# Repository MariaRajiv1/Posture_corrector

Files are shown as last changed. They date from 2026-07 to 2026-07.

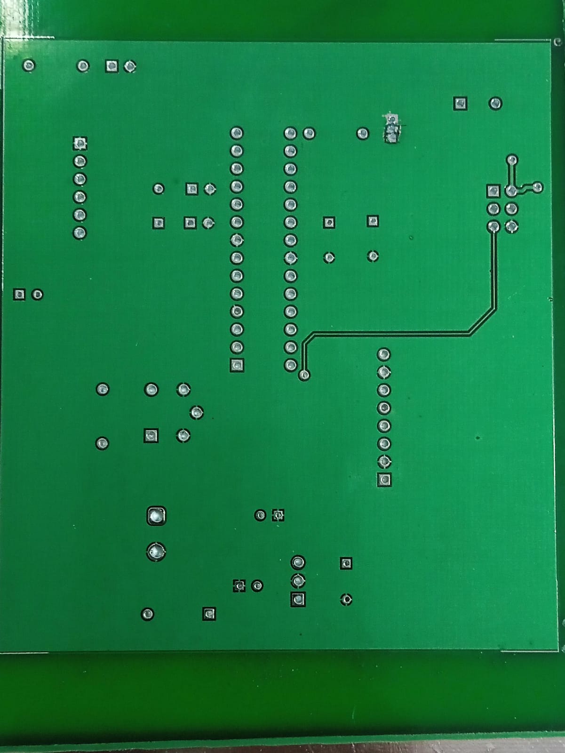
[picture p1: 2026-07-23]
images/fabricated pcb bottom layer.jpeg

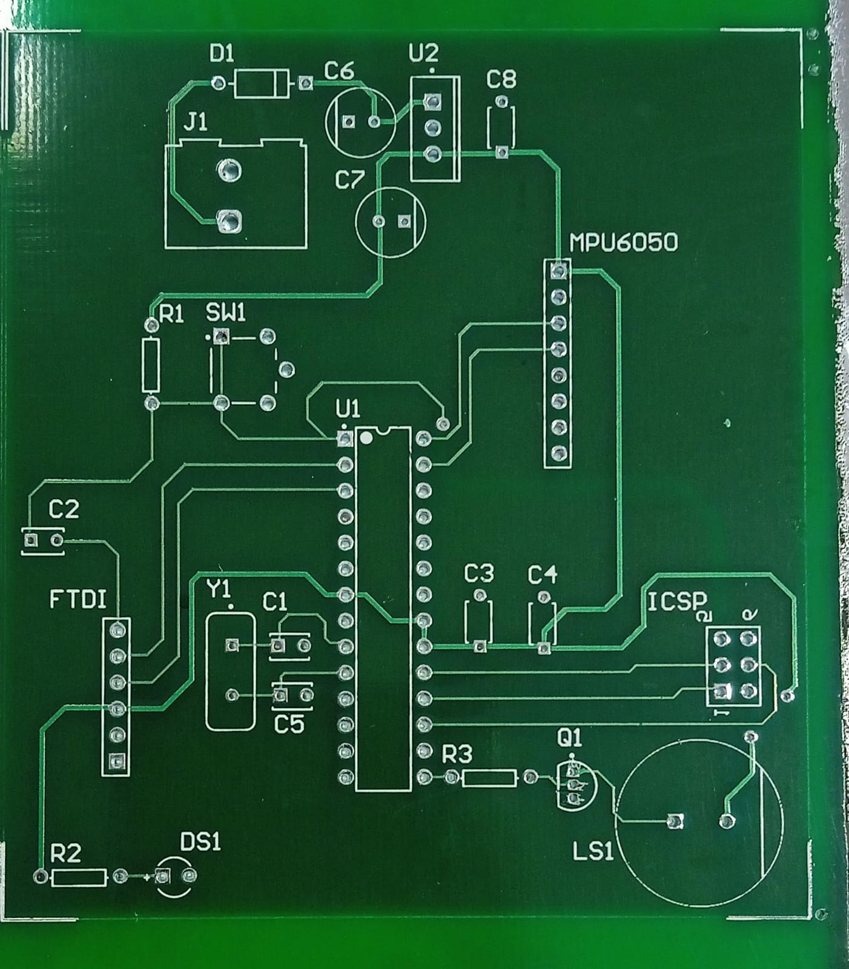
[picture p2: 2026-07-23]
images/fabricated pcb top layer.jpeg

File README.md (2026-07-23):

# Posture Corrector using ATmega328P and MPU6050

A wearable embedded system designed to monitor user posture in real time using the MPU6050 inertial measurement unit (IMU) and an ATmega328P microcontroller. The system detects prolonged poor posture and provides immediate feedback through an alert mechanism, encouraging users to maintain proper posture during daily activities.

This project was developed using a custom-designed PCB, demonstrating practical skills in embedded systems, PCB design, sensor interfacing, and hardware implementation.

---

## Features

- Real-time posture monitoring
- Slouch detection using MPU6050 IMU
- ATmega328P-based embedded system
- Custom PCB design
- Immediate posture correction alert
- Compact, wearable design
- Low-cost implementation

---

## Hardware Components

| Component | Description |
|---|---|
| ATmega328P | Main microcontroller |
| MPU6050 | 3-axis Accelerometer & Gyroscope |
| Buzzer / Vibration Motor | User alert mechanism |
| Voltage Regulator | Stable power supply |
| Battery | Portable power source |
| Custom PCB | Designed for compact implementation |

---

## Software Used

- Arduino IDE
- Embedded C
- I²C Communication Protocol
- MPU6050 Library

---

## Working Principle

1. The MPU6050 continuously measures the orientation of the user's upper body.
2. Sensor data is transmitted to the ATmega328P through I²C communication.
3. The microcontroller processes the orientation data and compares it with predefined posture thresholds.
4. If poor posture is maintained beyond the set duration, the system activates the alert mechanism.
5. The user corrects their posture, after which the system resumes monitoring.

---

## Repository Structure

```
Posture-Corrector/
│
├── README.md
├── docs/
├── hardware/
│   ├── Schematics/
│   └── PCB/
├── Gerbers/
├── firmware/
├── images/
├── reports/
└── results/

---

## Project Images

- Final Device
- Custom PCB
- Hardware Assembly
- Testing Setup
- Working Demonstration

---

## Results

- Successfully detects incorrect posture.
- Generates real-time alerts for prolonged slouching.
- Compact hardware implementation using a custom PCB.
- Suitable for wearable posture monitoring applications.

---

## Future Improvements

- Bluetooth connectivity
- Mobile application integration
- Rechargeable battery management
- Data logging
- Machine learning-based posture classification
- Miniaturized wearable enclosure

---

## Skills Demonstrated

- Embedded Systems
- PCB Design
- Sensor Interfacing
- ATmega328P Programming
- I²C Communication
- Hardware Debugging
- Wearable Electronics

---

## Authors

This project was developed by:

- Maria Rajiv
- Neha Savy
- Pavithra Mohan
- Suryadev G
  
B.Tech in Electronics and Communication Engineering

Mar Athanasius College of Engineering

---

## Acknowledgements

Special thanks to the project guide and team members for their support throughout the development of this project.

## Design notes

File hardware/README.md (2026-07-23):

# Hardware

This directory contains the complete hardware design files for the **Posture Corrector using ATmega328P and MPU6050**.

The hardware was developed to provide a compact, low-cost, and wearable solution for real-time posture monitoring. A custom printed circuit board (PCB) was designed to integrate the microcontroller, motion sensor, power supply, and supporting circuitry into a single embedded system.

## Directory Structure

### 📂 Schematics
Contains the complete circuit schematic of the posture corrector, including the ATmega328P microcontroller, MPU6050 IMU, power supply, programming interface, and alert circuitry.

### 📂 PCB
Contains the PCB layout, routing, board design files, and 3D renderings used during the hardware development process.

## Hardware Specifications

- **Microcontroller:** ATmega328P
- **Motion Sensor:** MPU6050 (3-axis Accelerometer + 3-axis Gyroscope)
- **Communication Protocol:** I²C
- **Alert Mechanism:** Buzzer / Vibration Motor
- **Power Supply:** Battery-powered
- **PCB Type:** Custom two-layer PCB

## Design Workflow

1. Circuit design and component selection
2. Schematic development
3. PCB layout and routing
4. Design Rule Check (DRC)
5. Gerber file generation
6. PCB fabrication
7. Component assembly and soldering
8. Hardware testing and validation

## Purpose

The hardware design demonstrates practical implementation of embedded electronics, including sensor interfacing, custom PCB design, power management, and wearable system development.

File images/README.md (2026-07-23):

# Images

This directory contains photographs and visual assets related to the **Posture Corrector using ATmega328P and MPU6050** project.

The images provide a visual overview of the hardware development, PCB fabrication, assembly process, and the final working prototype.

---

## Contents

### Final Prototype
Photographs of the completed wearable posture corrector.

### PCB
Images of the fabricated printed circuit board, including top and bottom views.

### Hardware Assembly
Photographs of the assembled electronic components and wiring.

### PCB Layout and 3D View
Rendered images of the PCB layout and 3D model generated during the design phase.

---

## Purpose

The images included in this directory document the development process and provide visual reference for the hardware implementation, making it easier to understand the overall design and construction of the project.

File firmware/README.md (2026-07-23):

# Firmware

This directory contains the firmware developed for the **Posture Corrector using the ATmega328P and MPU6050**.

The firmware is responsible for acquiring motion data from the MPU6050 IMU, processing the sensor readings to determine the user's posture, and activating an alert when poor posture is maintained beyond a predefined threshold. The software is optimized for real-time operation on the ATmega328P microcontroller.

---

## Features

- Real-time posture monitoring
- MPU6050 accelerometer and gyroscope interfacing
- I²C communication with the IMU
- Sensor data processing
- Posture angle calculation
- Configurable posture threshold
- Timer-based slouch detection
- Alert generation using a buzzer or vibration motor

---

## Development Environment

- **Microcontroller:** ATmega328P
- **Programming Language:** Embedded C/C++
- **Development Platform:** Arduino IDE
- **Communication Protocol:** I²C

---

## Firmware Workflow

1. Initialize the ATmega328P and MPU6050.
2. Read accelerometer and gyroscope data from the IMU.
3. Process the sensor data to determine the user's orientation.
4. Compare the measured posture with the predefined threshold.
5. If poor posture persists for the specified duration, activate the alert mechanism.
6. Continue monitoring until the posture returns to the acceptable range.

---

## Source Code

The firmware source code is provided in this directory and can be compiled and uploaded to the ATmega328P using the Arduino IDE.

---

## Notes

- Ensure the required libraries are installed before compiling the project.
- Verify the I²C connections between the ATmega328P and MPU6050 before uploading the firmware.
- Calibrate the MPU6050 sensor before testing to achieve accurate posture detection.

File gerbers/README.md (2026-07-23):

# Gerber Files

This directory contains the Gerber files generated from the final PCB design of the **Posture Corrector** project.

Gerber files are the standard manufacturing files used by PCB fabrication services to produce the printed circuit board. They include all the information required to manufacture the PCB, such as copper layers, solder mask, silkscreen, board outline, and drill data.

## Contents

- Copper layer files
- Solder mask files
- Silkscreen files
- Board outline
- NC drill files

## Usage

The files in this directory can be compressed into a ZIP archive and uploaded directly to PCB manufacturers such as **JLCPCB**, **PCBWay**, or **Seeed Fusion** for fabrication.

## Notes

- Generated from the final verified PCB layout.
- Ensure all Gerber files and drill files are included before submitting for fabrication.
- Perform a Gerber viewer check to verify the design before manufacturing.

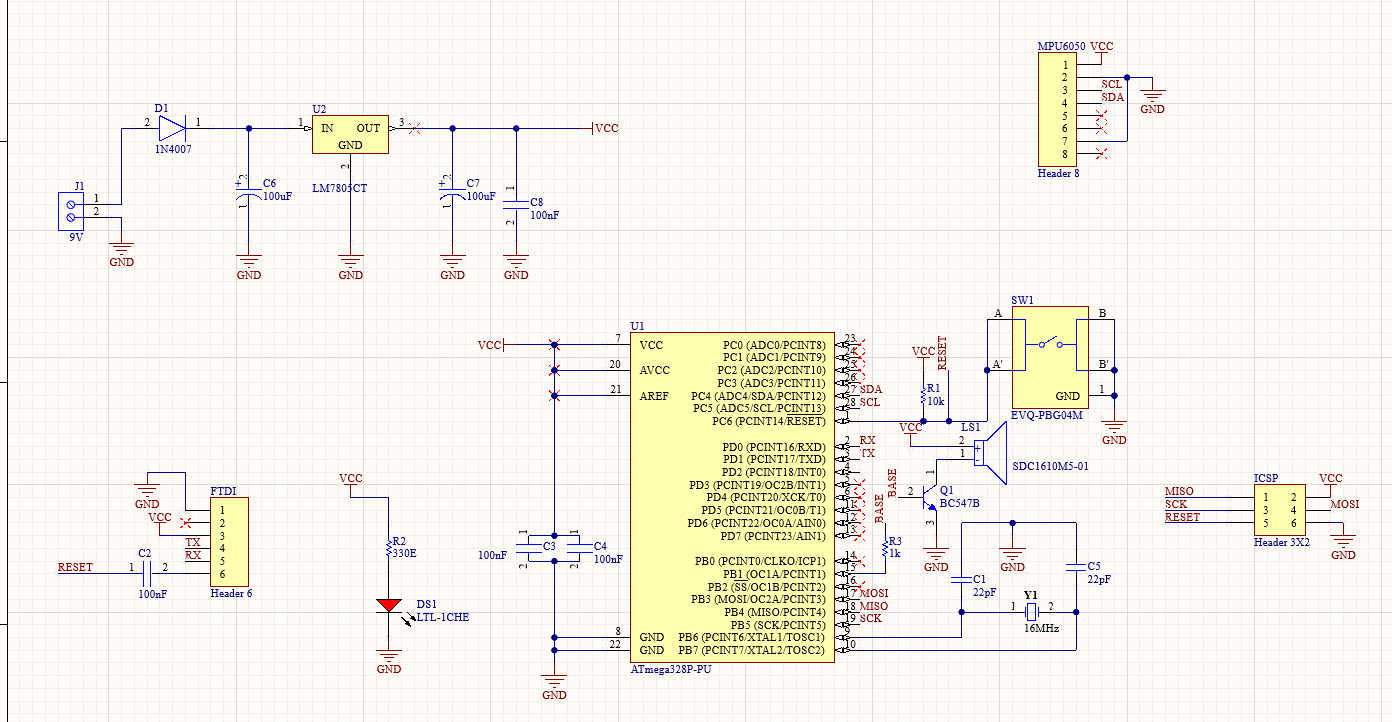
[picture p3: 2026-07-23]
images/schematic.png

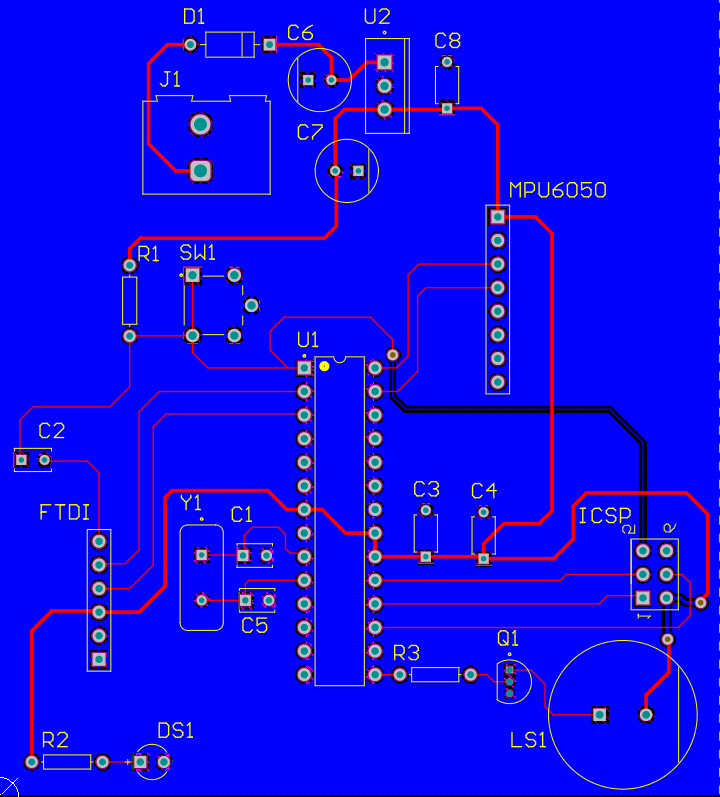
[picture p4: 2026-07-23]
images/pcb_design.png

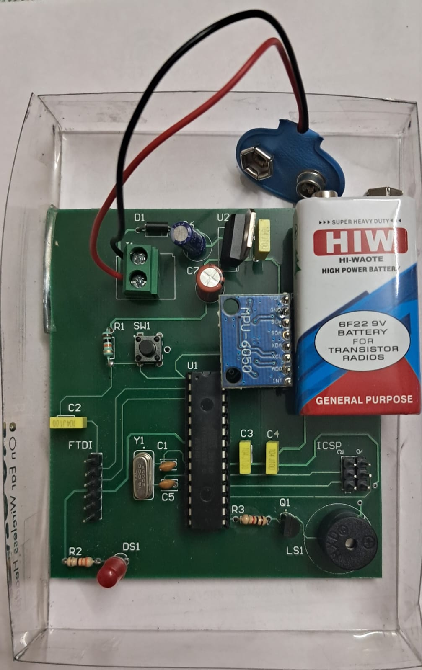
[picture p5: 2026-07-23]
images/completed pcb.jpeg

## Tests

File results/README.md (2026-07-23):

# Results

This directory contains the testing results and performance evaluation of the **Posture Corrector using ATmega328P and MPU6050**.

The results demonstrate the functionality of the system, including posture detection accuracy, alert response, and overall hardware performance under different testing conditions.

---

## Contents

### Functional Testing
Results obtained during system testing to verify correct operation of the hardware and firmware.

### Posture Detection
Observations of the system's ability to distinguish between correct and incorrect posture based on sensor data.

### Alert Mechanism
Verification of the buzzer or vibration motor response when poor posture is maintained beyond the predefined threshold.

### Calibration
Calibration data and test observations used to improve sensor accuracy and reliability.

### Demonstration
Screenshots, photographs, or recorded outputs showcasing the successful operation of the posture correction system.

---

## Summary

The implemented system successfully monitors body posture in real time using the MPU6050 IMU and ATmega328P microcontroller. The device detects prolonged poor posture and provides immediate feedback through the alert mechanism, demonstrating the feasibility of a compact and low-cost wearable posture monitoring solution.

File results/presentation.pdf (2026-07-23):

# MINI PROJECT PRESENTATION

GROUP 10

Maria Rajiv (MAC23EC079)
Neha Savy (MAC23EC096)
Pavithra Mohan (MAC23EC097) Suryadev G (MAC23EC120)

MAR ATHANASIUS COLLEGE OF ENGINEERING, KOTHAMANGALAM

DEPARTMENT OF ELECTRONICS AND COMMUNICATION ENGINEERING

## COURSE CODE : ECD334

## PHASE I & II

# CONTENTS

- Introduction ● Objectives ● Components Required ● Block Diagram ● Working Principle ● Features ● Design & Implementation ● Results ● Challenges ● Applications & Future scope
- Working Principle ● Design ● Components Required ● Circuit Diagram ● Schematic Diagram ● PCB Layout ● Fabrication steps ● Output & Results ● Challenges ● Applications & Future scope

# WHY POSTURE CORRECTION MATTERS ?

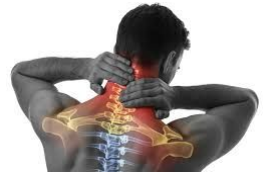
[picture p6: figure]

- Extended sitting is common among students and IT professionals
- Improper posture causes neck pain, back pain, and muscle fatigue
- Sustained poor posture may lead to cervical spondylosis, back strain, and stiffness

# WHAT IS CONSIDERED GOOD POSTURE ?

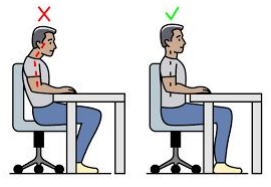
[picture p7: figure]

- Good posture maintains a near-neutral spine
- A small natural curve in the back is maintained
- Posture is personalized, not based on a single fixed angle

# OBJECTIVES

- To design a wearable posture correction system
- To implement posture detection using MPU6050 sensor data
- To process orientation data using the ATmega328P microcontroller
- To perform baseline calibration for user-specific posture adaptation
- To generate corrective feedback using a buzzer alert system
- To develop a custom-designed PCB for a compact embedded solution
- To validate the system through fabricated hardware testing

# HARDWARE COMPONENTS

- ATmega328P microcontroller
- MPU6050 sensor
- Buzzer
- BC547 transistor
- 7805 voltage regulator
- 16 MHz crystal oscillator
- capacitors, resistors, reset switch
- FTDI and ICSP programming headers
- 9V power input

# BLOCK DIAGRAM

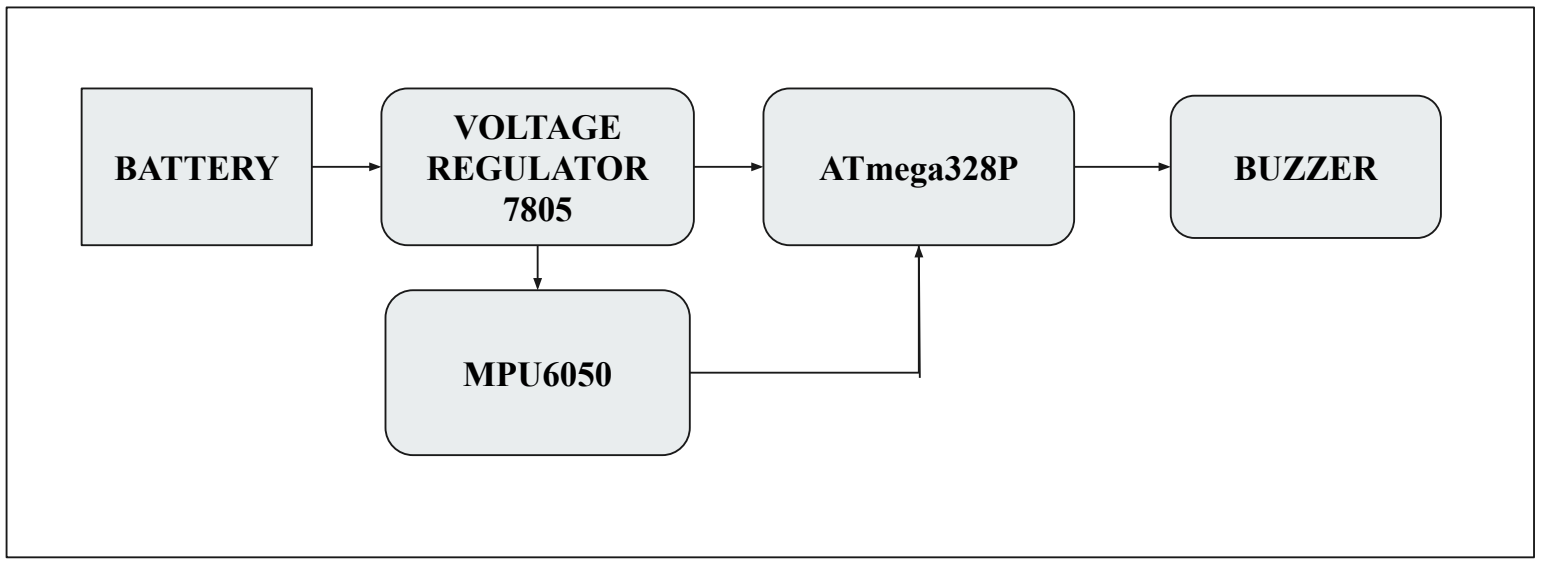
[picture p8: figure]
BATTERY; VOLTAGE REGULATOR 7805; ATmega328P; MPU6050; BUZZER

# WORKING PRINCIPLE

1. Device powers on → a startup beep confirms readiness
2. Good posture is recorded as baseline pitch
3. Sensor continuously measures current tilt
4. Controller computes corrected pitch = current pitch − baseline
5. If slouch exceeds threshold for a 3 seconds, buzzer sounds
6. If posture becomes worse, beep rate increases
7. When posture is corrected, alert stops

# WORKING PRINCIPLE

MPU6050 communicates over I²C and provides:

- Accelerometer output as linear acceleration along X, Y, Z axes (in m/s²)
- Converted into angle (degrees)

Where ay and az are acceleration components

# FEATURES

### 1. Baseline Calibration

- On startup, the user is prompted: "Hold good posture for calibration"
- After a 2-second settle delay, one accelerometer reading is captured
- This pitch value becomes baseline pitch — stored for the entire session
- All subsequent readings are subtracted from this baseline

corrected pitch = current pitch − baseline pitch

# FEATURES

### 2. Decision Logic and Adaptive Alert System

Beep frequency: 2000 Hz, duration: 120 ms

CONDITION | ANGLE | BEEP INTERVAL
Good Posture | <14° | No Beep
Bad Posture | 18-30° | Every 2 seconds
Very Bad Posture | >30° | Every 700 ms

# FEATURES

### 3. False Alert Prevention

- Short-term bending (like picking objects) should not trigger alert
- Solution implemented:

3-second delay before alert

Neutral zone (<5°) resets system

Filtering removes sudden spikes

- Only continuous bad posture triggers buzzer

# SIMULATION USING WOKWI

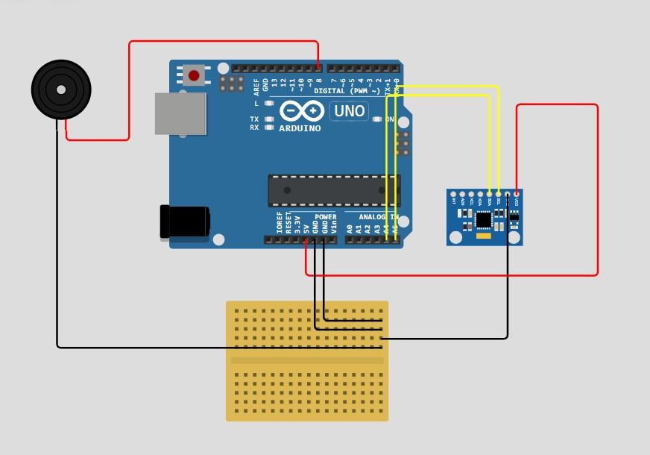
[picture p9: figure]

FIG 1: POSTURE CORRECTOR IMPLEMENTED USING ARDUINO UNO

## SCHEMATIC DESIGN USING ALTIUM

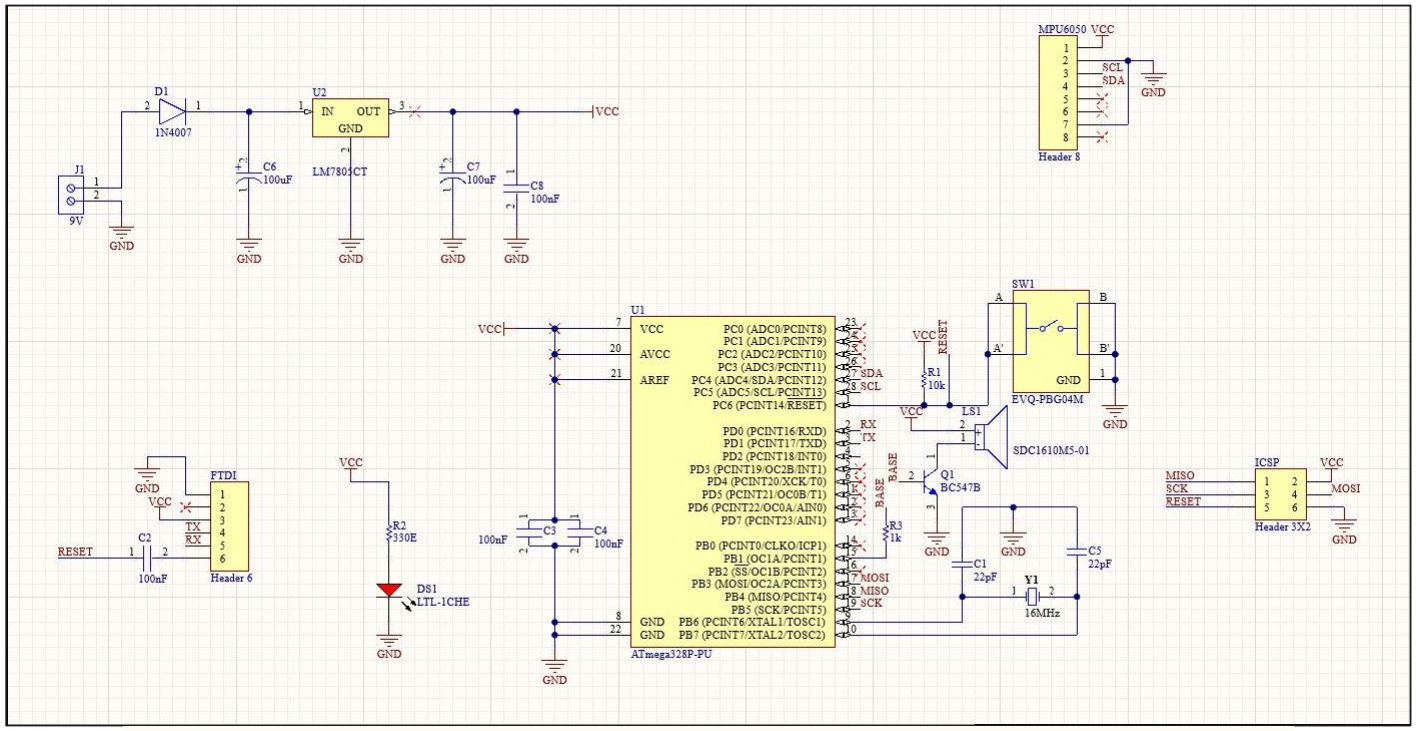
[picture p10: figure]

FIG 2 : SCHEMATIC DESIGN OF POSTURE CORRECTOR USING ATMEGA328P

# CIRCUIT OVERVIEW

### 1. Power Section

Regulated 5V Power Supply

- Input: 9V external supply
- 1N4007 diode — reverse polarity protection, prevents damage if battery is connected backwards
- LM7805 — linear voltage regulator, steps down 9V → stable 5V
- 100µF capacitor — bulk filtering, absorbs low-frequency voltage fluctuations
- 100nF capacitor — high-frequency noise decoupling, keeps supply clean at the IC pins

# CIRCUIT OVERVIEW

### 2. Microcontroller Core

ATmega328P

- Heart of the system — runs all posture logic, timing, and I²C communication
- 16 MHz crystal (Y1) — provides precise clock reference
- 22pF capacitors (C1, C5) — load capacitors for crystal stability

# CIRCUIT OVERVIEW

### 2. MPU6050 Interface

- Communicates with ATmega328P over I²C protocol (2-wire)
- SDA → PC4 (Arduino A4) — Serial Data line
- SCL → PC5 (Arduino A5) — Serial Clock line
- Powered directly from the board's regulated VCC and GND

# CIRCUIT OVERVIEW

### 4. Programming Interfaces

- Two Ways to Program the Board
- Having both makes the board flexible for all stages of development
INTERFACE | PINS USED | PURPOSE
FTDI (UART) | TX,RX | Upload sketches via USB-to-Serial adapter
ICSP (SPI) | MOSI, MISO, SCK, RESET | Burn bootloader

# CIRCUIT OVERVIEW

### 5. Buzzer Drive Circuit — BC547 Transistor

- ATmega328P GPIO can only source ~40mA — not enough to drive a buzzer directly
- BC547 NPN transistor acts as a switch, allowing the buzzer to draw current from VCC
- Base resistor (R3) — limits base current, protects the microcontroller's GPIO pin
- Buzzer (LS1) — driven safely through the collector with full supply voltage

# PCB Implementation

- Custom standalone ATmega328P design
- I2C connection to MPU6050
- Transistor-driven buzzer
- Onboard reset and programming support
- Compact PCB for final implementation

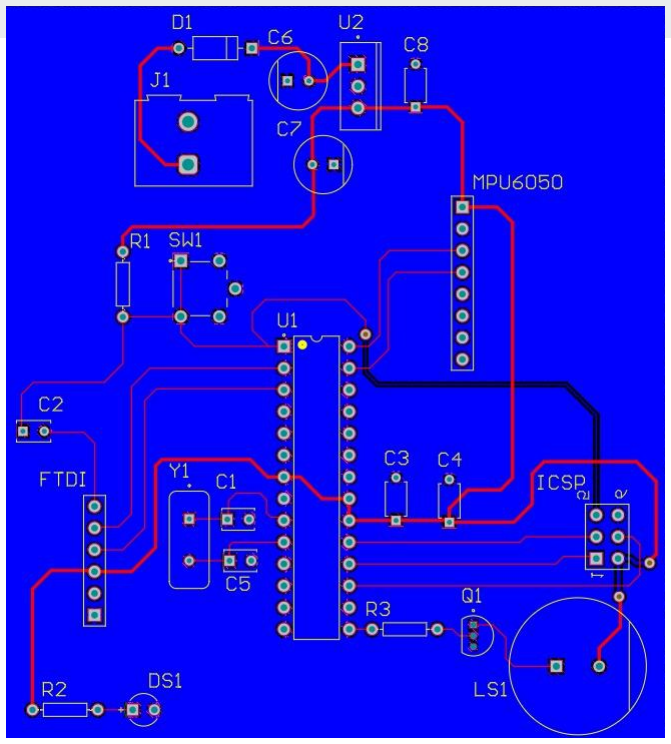
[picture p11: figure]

FIG 3 : PCB LAYOUT USING ALTIUM

# FABRICATED PCB

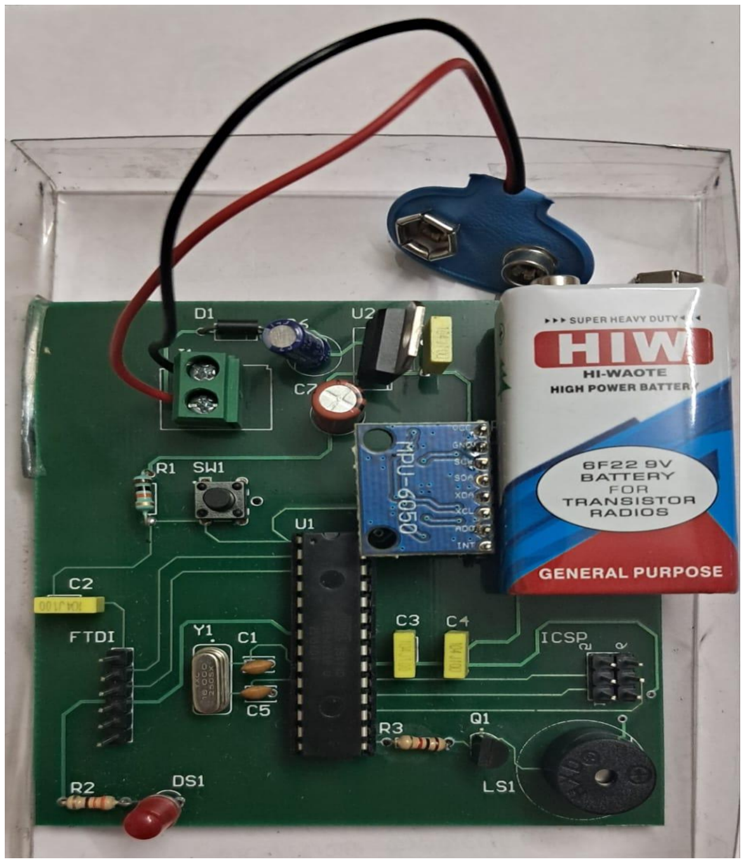
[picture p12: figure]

# HARDWARE VALIDATION

- Verified I2C communication with MPU6050
- Observed real-time angle via Serial Monitor
- Tested:

Straight posture → no beep

Slouch → delayed alert

Severe slouch → fast alert

# Existing Wearables vs Our Approach

TYPICAL WEARABLE POSTURE
CORRECTOR

SMART POSTURE CORRECTOR

- Usually Strap-Based Or Brace-Based
- Physically Force The Shoulders/Back Into Position
- Can Feel Uncomfortable
- May Create Dependence Instead Of Awareness
- Not Suitable For Long-Term Use
- Does Not Force Posture Mechanically
- Monitors Posture Electronically
- Gives Feedback Only When Needed
- Supports Habit Formation Through Repeated Feedback
- More Like Training The User Than Restraining The User

# CHALLENGES FACED

- Pad sizes on certain footprints were undersized, making clean solder joints harder to achieve for some components.
- Raw accelerometer output contained high-frequency noise, causing the calculated pitch angle to fluctuate continuously → Implemented a low-pass filter in software to smooth readings

# LIMITATIONS

- Sensitive to movement: Accurate mainly when seated; walking/dynamic motion reduces pitch accuracy.
- No data logging: Operates in real-time only; no history or progress tracking available.

# APPLICATIONS

- Students and office workers
- Rehabilitation Therapy
- Fitness and posture training
- Long duration computer users

# FUTURE SCOPE

- Vibration motor instead of buzzer
- Rechargeable battery
- Smaller wearable enclosure
- Mobile app integration
- Posture logging and analytics

# THANK YOU

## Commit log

2026-07-23 Add files via upload
    The schematic represents the hardware design of the posture correction system. It includes the ATmega328P microcontroller, MPU6050 inertial measurement unit (IMU), voltage regulation circuit, ISP programming header, crystal oscillator, reset circuitry, and output alert device. All peripheral connections and power distribution required for system operation are shown.
    [Sheet2.SchDoc]
2026-07-23 Add files via upload
    A custom PCB was designed to integrate all the essential components of the posture correction system into a compact and reliable hardware platform. The board accommodates the ATmega328P microcontroller, MPU6050 IMU, power supply circuitry, programming header, and alert mechanism while ensuring proper signal routing and power distribution.
    The PCB replaces the need for development boards, resulting in a smaller, more efficient, and wearable implementation suitable for embedded applications.
    [Posture_corrector_pcb_design.PcbDoc]
2026-07-23 Expand README with Gerber files information
    Added detailed information about Gerber files and their usage for PCB fabrication.
